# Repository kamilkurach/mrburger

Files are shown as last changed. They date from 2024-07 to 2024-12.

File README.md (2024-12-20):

# mrburger - mobile robot

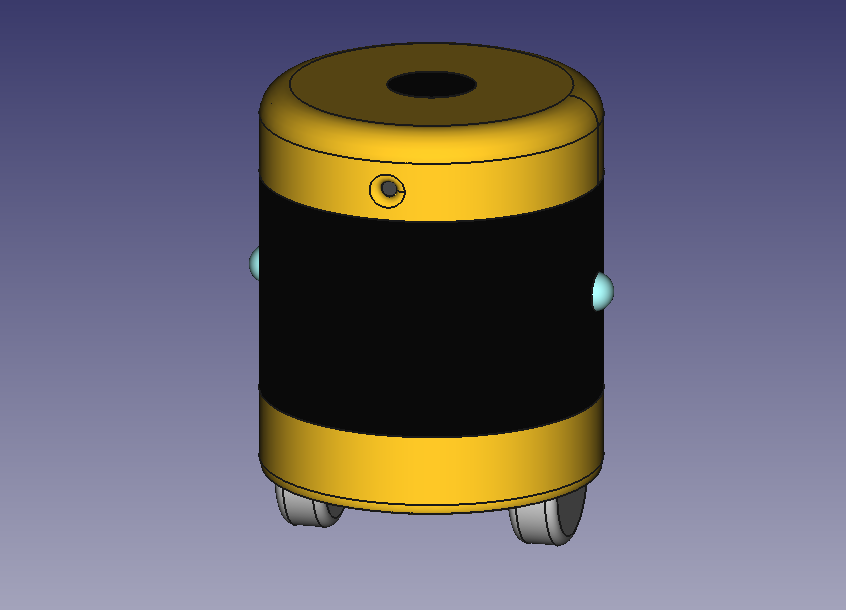
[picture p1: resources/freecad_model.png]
freecad

<!-- <img src="resources/IMG_20241218_102031.jpg" alt="currentstate" width=30%/> -->

## current state:

<!-- <img src="resources/IMG_20241204_015451.jpg" alt="currentstate" width=30%/> -->
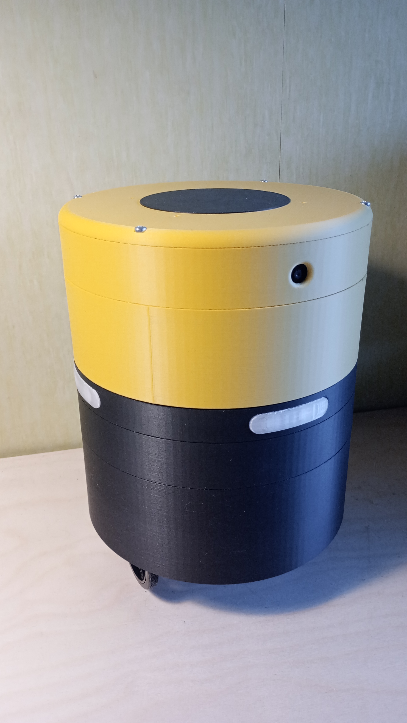
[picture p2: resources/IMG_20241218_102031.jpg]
currentstate


HARDWARE progress

SOFTWARE progress

## videos: 

https://youtube.com/shorts/dS5dcS42dTs

https://youtube.com/shorts/08CZh5qDslI

https://youtube.com/shorts/WGJIwH7I2C0 *latest*

## additional info and multimedia:

https://x.com/kamil_kurach

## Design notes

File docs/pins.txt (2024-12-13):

#GPIO12 PWMA -> PWM hardware pin (less overhead on CPU)

#GPIO13 PWMB -> PWM hardware pin (less overhead on CPU)

#GPIO4 STBY -> power saving on/off

#GPIO6 AIN2 -> controls motor spin direction

#GPIO5 AIN1 -> controls motor spin direction

#GPIO26 BIN1 -> controls motor spin direction

#GPIO19 BIN2 -> controls motor spin direction

#GPIO22 -> gpio-shutdown button

#GPIO27 -> 

#GPIO10 -> led SPI0

#GPIO2 SDA -> 9DoF IMU 
   
#GPIO3 SCL -> 9DoF IMU

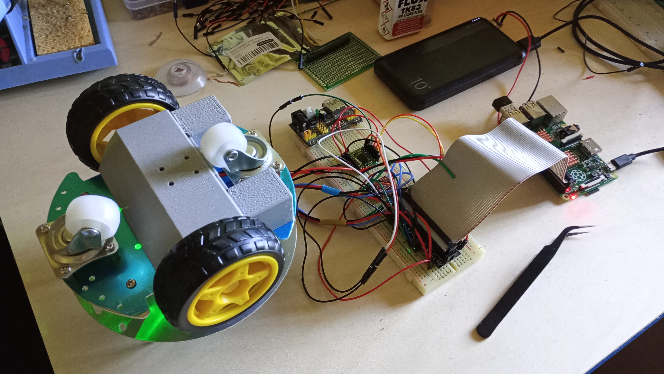
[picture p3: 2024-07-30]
resources/IMG_20240730_090038_dust_cover.jpg

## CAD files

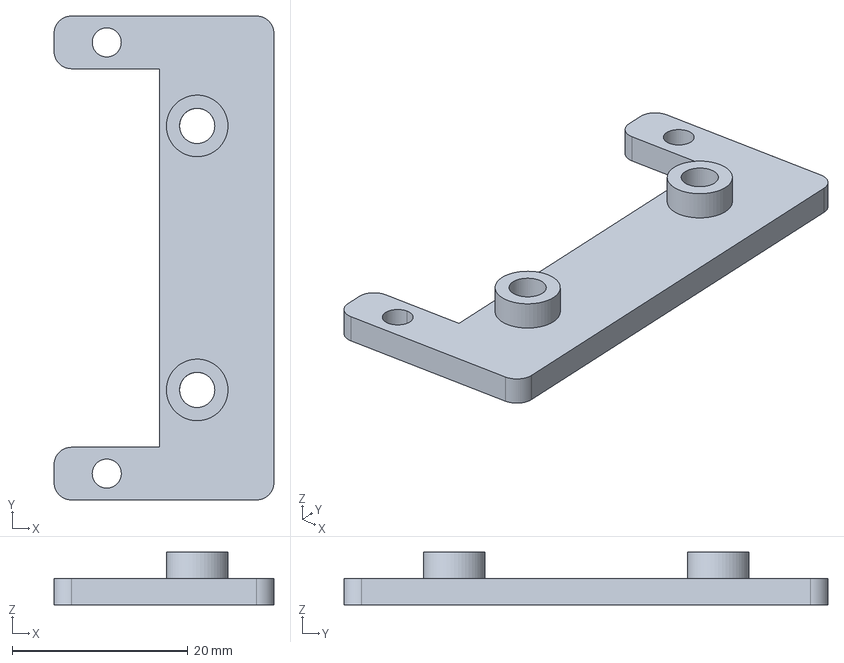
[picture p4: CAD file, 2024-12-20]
freecad/mrburger_usb_switch_panel_bracket.FCStd
25.0 x 55.0 x 6.00 mm

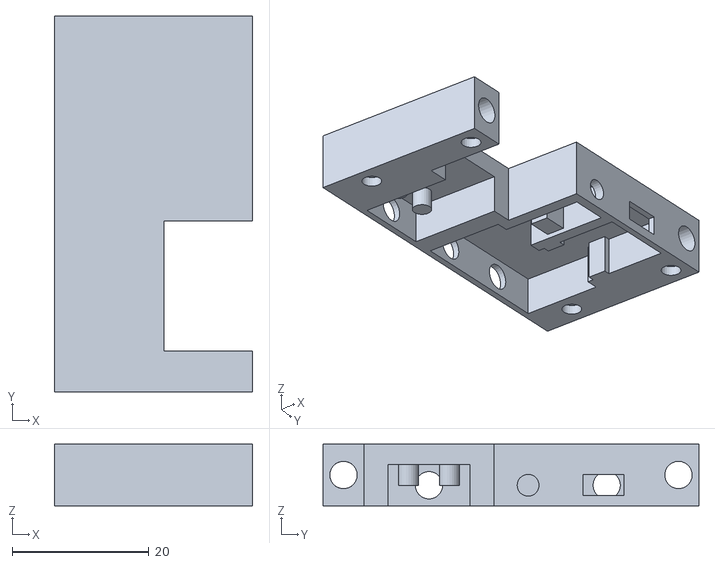
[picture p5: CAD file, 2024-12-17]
stl/mrburger_usb_switch_panel_bottom_panel.stl
29.0 x 55.0 x 9.00

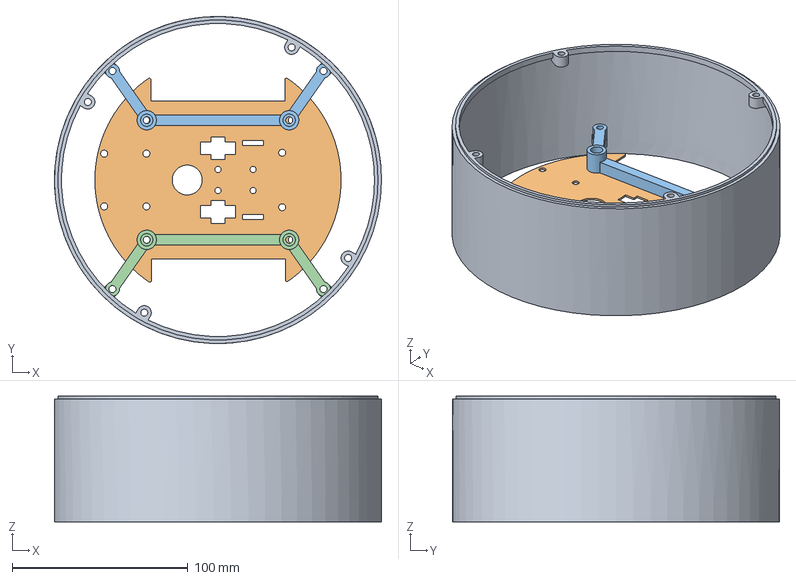
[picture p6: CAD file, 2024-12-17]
freecad/mrburger_bottom_ring.FCStd
186.0 x 186.0 x 71.5 mm
bottom_ring
mrburger_bottom_plate
mrburger_bracket_2
mrburger_bracket_003

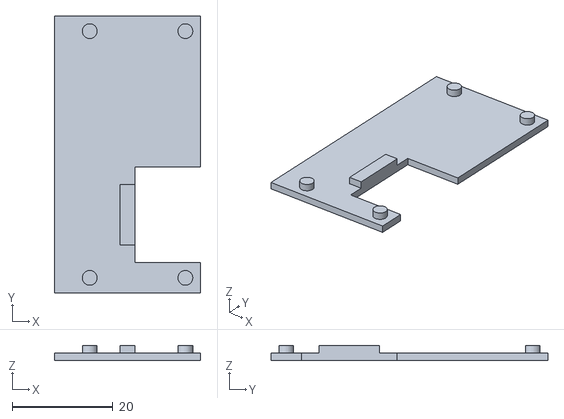
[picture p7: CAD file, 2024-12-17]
stl/mrburger_usb_switch_panel_lid.stl
29.0 x 55.0 x 3.00

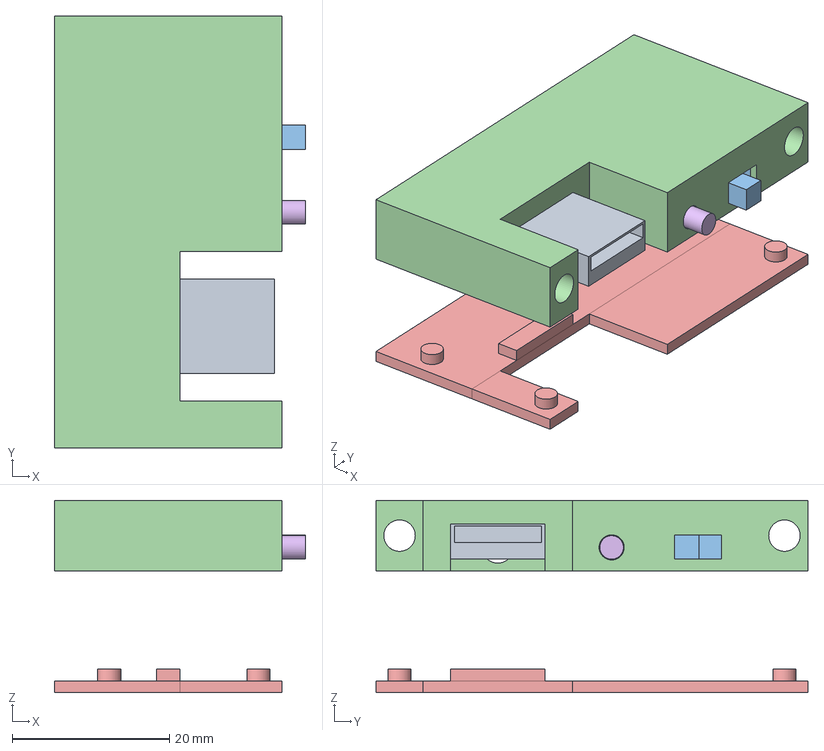
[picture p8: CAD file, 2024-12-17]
freecad/mrburger_usb_switch_panel.FCStd
32.0 x 55.0 x 24.5 mm
usb_type_A
push_button
switch
panel
lid
push_button_pin

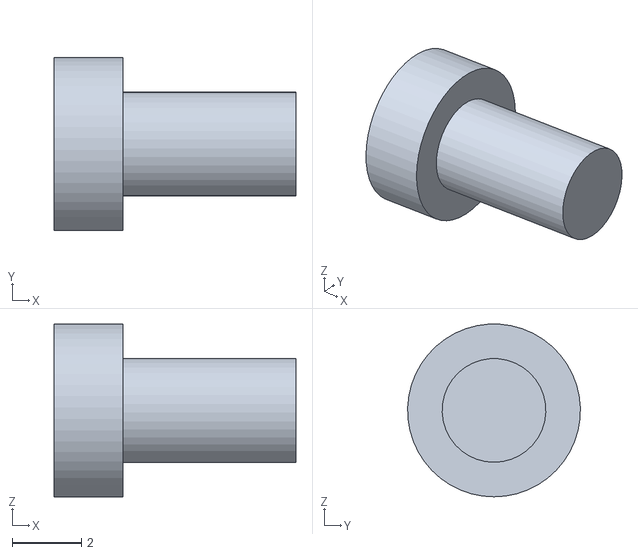
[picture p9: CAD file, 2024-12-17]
stl/mrburger_usb_switch_panel_button_pin.stl
7.00 x 5.00 x 4.99

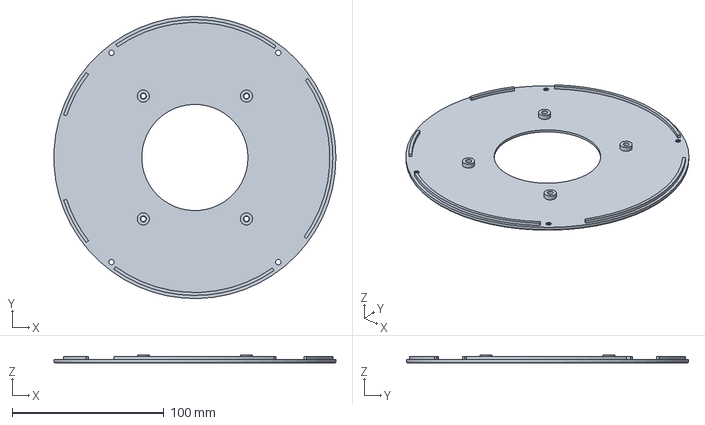
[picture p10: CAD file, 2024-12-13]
freecad/mrburger_universal_top_hat.FCStd
185.9 x 185.9 x 5.50 mm

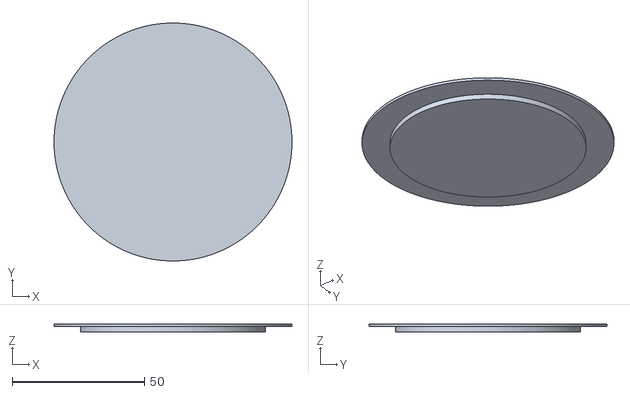
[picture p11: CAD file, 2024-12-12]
stl/mrburger_black_lid.stl
90.0 x 90.0 x 3.00

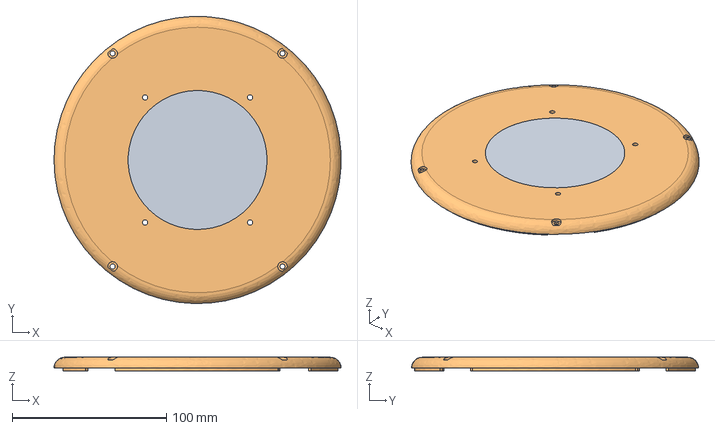
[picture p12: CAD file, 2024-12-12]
freecad/mrburger_top_hat.FCStd
185.9 x 185.9 x 8.80 mm
black_lid
yellow_hat

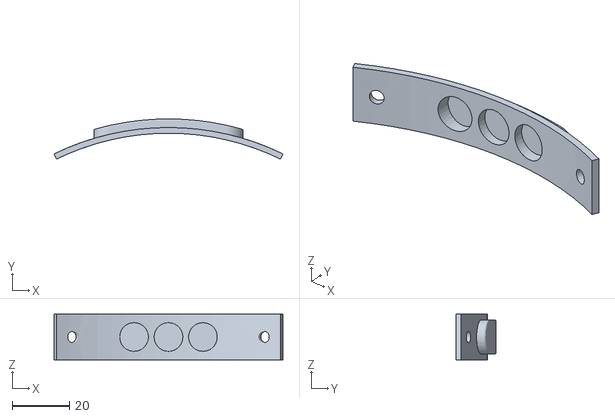
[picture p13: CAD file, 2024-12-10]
stl/mrburger_mid_led_ring_2_led_cover_2.2.stl
79.8 x 14.0 x 16.0

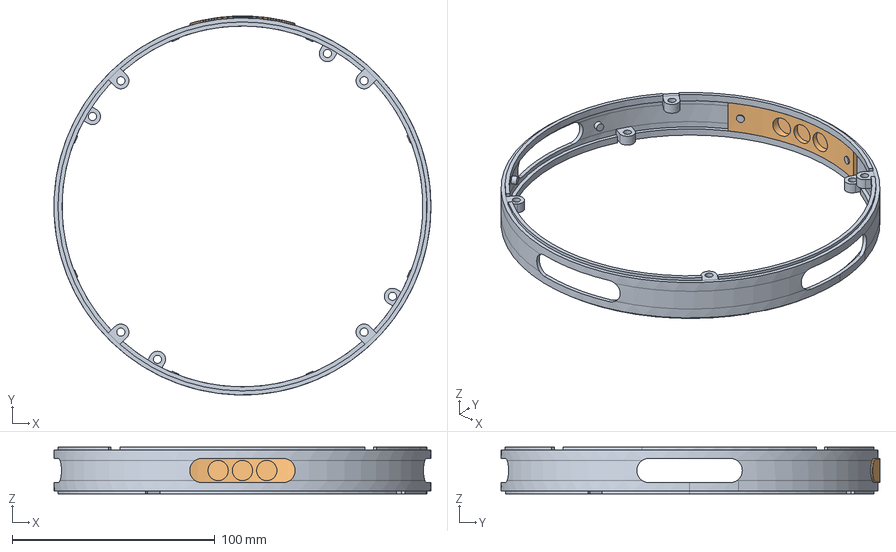
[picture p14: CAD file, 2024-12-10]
freecad/mrburger_mid_led_ring_2.2.FCStd
186.0 x 186.9 x 23.0 mm
led_ring
led_cover

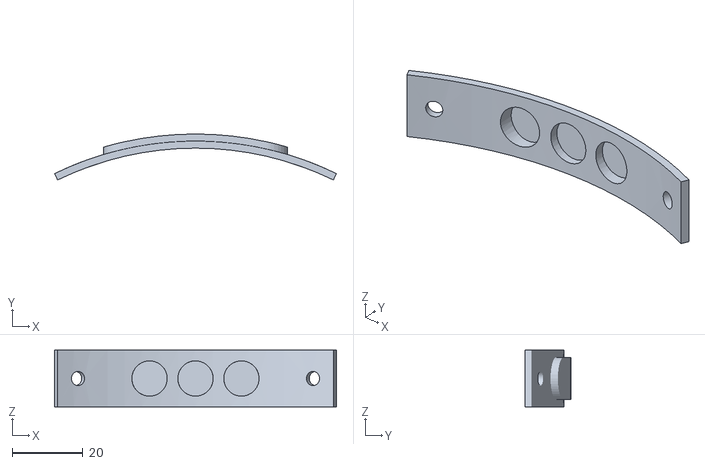
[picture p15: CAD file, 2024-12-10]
stl/mrburger_mid_led_ring_2_led_cover.stl
79.8 x 13.0 x 16.0

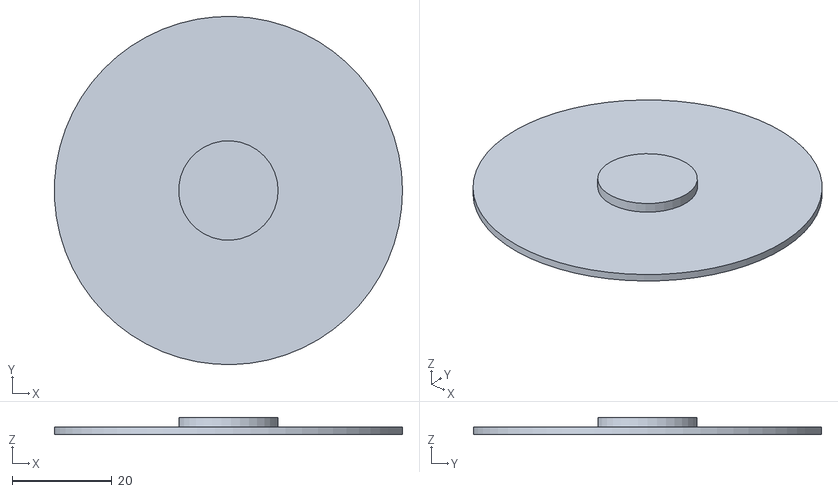
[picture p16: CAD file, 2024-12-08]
stl/mrburger_universal_black_lid.stl
70.0 x 70.0 x 3.50

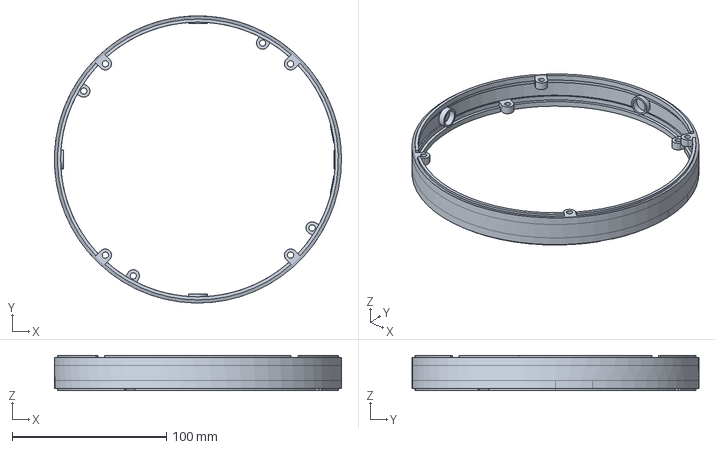
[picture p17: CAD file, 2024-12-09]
freecad/mrburger_mid_led_ring.FCStd
186.0 x 186.0 x 23.0 mm

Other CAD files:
freecad/mrburger_mid_led_ring_2.FCStd
stl/mrburger_induction_coil_bracket_coil_cover.stl
freecad/mrburger_bottom_hat.FCStd
stl/mrburger_induction_coil_bracket_electronics_cover.stl
freecad/mrburger_Li-Po_power_tray.FCStd
freecad/mrburger_bottom.FCStd
freecad/mrburger_bottom_plate.FCStd
freecad/mrburger_bracket.FCStd
freecad/mrburger_bracket_2.FCStd
freecad/mrburger_camera_bracket.FCStd
freecad/mrburger_camera_module.FCStd
freecad/mrburger_chassis.FCStd
freecad/mrburger_encoder_dust_cover.FCStd
freecad/mrburger_encoder_dust_cover_2.FCStd
freecad/mrburger_encoder_dust_cover_3.FCStd
freecad/mrburger_encoder_spacer.FCStd
freecad/mrburger_fan_inlet.FCStd
freecad/mrburger_hat.FCStd
freecad/mrburger_hat_light.FCStd
freecad/mrburger_imu.FCStd
freecad/mrburger_imu_mount.FCStd
freecad/mrburger_imu_pin.FCStd
freecad/mrburger_induction_coil_bracke_2.FCStd
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

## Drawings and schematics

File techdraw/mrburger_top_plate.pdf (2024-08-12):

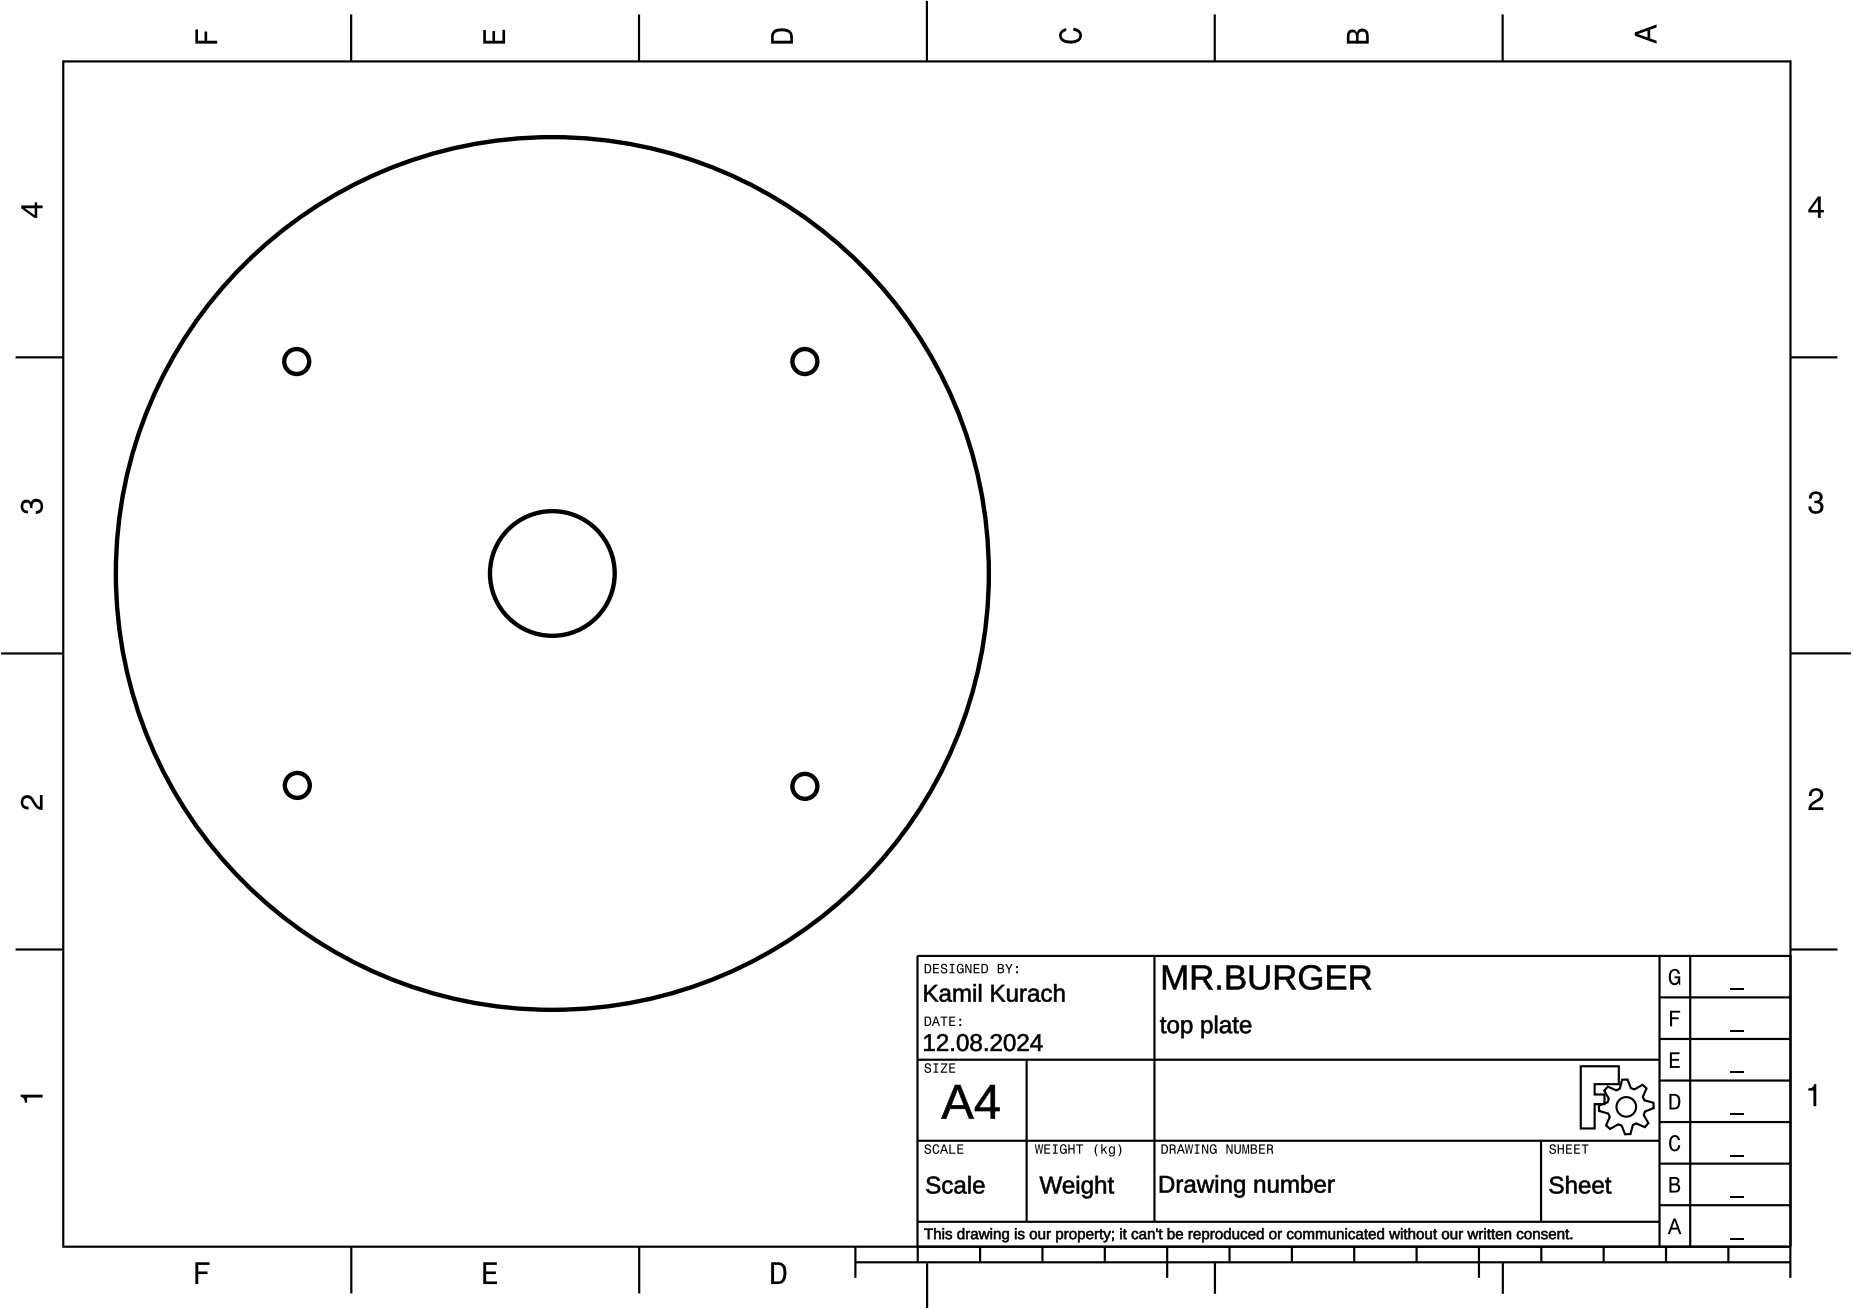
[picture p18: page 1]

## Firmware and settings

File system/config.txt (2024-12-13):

# For more options and information see
# http://rptl.io/configtxt
# Some settings may impact device functionality. See link above for details

# Uncomment some or all of these to enable the optional hardware interfaces
dtparam=i2c_arm=on
#dtparam=i2s=on
dtparam=spi=on

# Enable audio (loads snd_bcm2835)
dtparam=audio=off

# Additional overlays and parameters are documented
# /boot/firmware/overlays/README

# Automatically load overlays for detected cameras
camera_auto_detect=1

# Automatically load overlays for detected DSI displays
display_auto_detect=1

# Automatically load initramfs files, if found
auto_initramfs=1

# Enable DRM VC4 V3D driver
dtoverlay=vc4-kms-v3d
max_framebuffers=2

# Don't have the firmware create an initial video= setting in cmdline.txt.
# Use the kernel's default instead.
disable_fw_kms_setup=1

# Disable compensation for displays with overscan
disable_overscan=1

# Run as fast as firmware / board allows
arm_boost=1

# push button off
dtoverlay=gpio-shutdown,gpio_pin=22

[cm4]
# Enable host mode on the 2711 built-in XHCI USB controller.
# This line should be removed if the legacy DWC2 controller is required
# (e.g. for USB device mode) or if USB support is not required.
otg_mode=1

[cm5]
dtoverlay=dwc2,dr_mode=host

[all]
#arm_freq=800
#core_freq=250
#sdram_freq=400
#over_voltage=0
enable_uart=1

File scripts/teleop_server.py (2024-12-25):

import RPi.GPIO as GPIO
import pigpio
from time import sleep
import threading
import sys
import socket
from led import right_turn, left_turn, stop_light, forward_light_on, forward_light_off

GPIO.setmode(GPIO.BCM)

#GPIO12 PWMA
#GPIO.setup(12, GPIO.OUT)
#GPIO13 PWMB
#GPIO.setup(13, GPIO.OUT)

#GPIO4 STBY
GPIO.setup(4, GPIO.OUT)
GPIO.output(4, GPIO.HIGH)

def backwards():
  #GPIO6 AIN2
  GPIO.setup(6, GPIO.OUT)
  GPIO.output(6, GPIO.HIGH)

  #GPIO5 AIN1
  GPIO.setup(5, GPIO.OUT)
  GPIO.output(5, GPIO.LOW)

  #GPIO26 BIN1
  GPIO.setup(26, GPIO.OUT)
  GPIO.output(26, GPIO.LOW)

  #GPIO19 BIN2
  GPIO.setup(19, GPIO.OUT)
  GPIO.output(19, GPIO.HIGH)

def forward():
  #GPIO6 AIN2
  GPIO.setup(6, GPIO.OUT)
  GPIO.output(6, GPIO.LOW)

  #GPIO5 AIN1
  GPIO.setup(5, GPIO.OUT)
  GPIO.output(5, GPIO.HIGH)

  #GPIO26 BIN1
  GPIO.setup(26, GPIO.OUT)
  GPIO.output(26, GPIO.HIGH)

  #GPIO19 BIN2
  GPIO.setup(19, GPIO.OUT)
  GPIO.output(19, GPIO.LOW)

def turn_right():
  #GPIO6 AIN2
  GPIO.setup(6, GPIO.OUT)
  GPIO.output(6, GPIO.HIGH)

  #GPIO5 AIN1
  GPIO.setup(5, GPIO.OUT)
  GPIO.output(5, GPIO.LOW)

  #GPIO26 BIN1
  GPIO.setup(26, GPIO.OUT)
  GPIO.output(26, GPIO.HIGH)

  #GPIO19 BIN2
  GPIO.setup(19, GPIO.OUT)
  GPIO.output(19, GPIO.LOW)

def turn_left():
  #GPIO6 AIN2
  GPIO.setup(6, GPIO.OUT)
  GPIO.output(6, GPIO.LOW)

  #GPIO5 AIN1
  GPIO.setup(5, GPIO.OUT)
  GPIO.output(5, GPIO.HIGH)

  #GPIO26 BIN1
  GPIO.setup(26, GPIO.OUT)
  GPIO.output(26, GPIO.LOW)

  #GPIO19 BIN2
  GPIO.setup(19, GPIO.OUT)
  GPIO.output(19, GPIO.HIGH)

def soft_stop():
  #GPIO6 AIN2
  GPIO.setup(6, GPIO.OUT)
  GPIO.output(6, GPIO.LOW)

  #GPIO5 AIN1
  GPIO.setup(5, GPIO.OUT)
  GPIO.output(5, GPIO.LOW)

  #GPIO26 BIN1
  GPIO.setup(26, GPIO.OUT)
  GPIO.output(26, GPIO.LOW)

  #GPIO19 BIN2
  GPIO.setup(19, GPIO.OUT)
  GPIO.output(19, GPIO.LOW)


#left sensor
GPIO.setup(22, GPIO.IN)
#right sensor
GPIO.setup(27, GPIO.IN)

#set gpio25 to 50Hz
#pwm_a = GPIO.PWM(12, 50)
#pwm_b = GPIO.PWM(13, 50)

PI = pigpio.pi()
#PI.hardware_PWM(12, 50000, 400000)
#PI.hardware_PWM(13, 50000, 400000)

#pwm_a.start(0)
#pwm_b.start(0)

#set global vars initial values
PREV_TICK = GPIO.input(22)
TOTAL_TICKS = 0
TARGET_REACHED = False

'''
def calc_distance(tick_count):
  #returned distance in mm
  #wheel circumference 67 mm
  tick_per_revolution = 40
  distance = 67 * tick_count/tick_per_revolution
  return distance

def count_ticks(gpio):
  global TOTAL_TICKS
  global PREV_TICK
  global TARGET_REACHED
  while True:
    left_encoder = GPIO.input(gpio)
    if left_encoder == 1 and PREV_TICK == 0:
      TOTAL_TICKS += 1
    elif left_encoder == 0 and PREV_TICK == 1:
      TOTAL_TICKS += 1
    PREV_TICK = left_encoder
  #print("TT: ",TOTAL_TICKS,"PT: ",PREV_TICK)

def print_sensor_data():
  left_encoder = GPIO.input(22)
  right_encoder = GPIO.input(27)
  print("L: ", left_encoder, "R: ", right_encoder)

'''
#t_r = threading.Thread(target=right_turn, args=(3,))
#t.start()
#t_l = threading.Thread(target=left_turn, args=(3,))

host = '192.168.5.111'
socket = socket.socket(socket.AF_INET, socket.SOCK_STREAM)
socket.bind((host, 8080))
socket.listen(1)
connection, address = socket.accept()

current_state = None

forward_light_on()

while True:
  buffer = connection.recv(1024)
  if len(buffer) > 0:
    if str(buffer.decode()) == 'w':
      print(buffer)
      #soft_stop()
      #pwm_a.ChangeDutyCycle(0)
      #pwm_b.ChangeDutyCycle(0)
      #sleep(0.1)
      forward()
      PI.hardware_PWM(12, 50000, 400000)
      PI.hardware_PWM(13, 50000, 400000)
      #pwm_a.ChangeDutyCycle(40)
      #pwm_b.ChangeDutyCycle(40)
    elif str(buffer.decode()) == 'x':
      forward()
      PI.hardware_PWM(12, 50000, 650000)
      PI.hardware_PWM(13, 50000, 650000)
    elif str(buffer.decode()) == 's':
      print(buffer)
      soft_stop()
      #pwm_a.ChangeDutyCycle(0)
      #pwm_b.ChangeDutyCycle(0)
      PI.hardware_PWM(12, 50000, 0)
      PI.hardware_PWM(13, 50000, 0)
      sleep(0.2)
      backwards()
      PI.hardware_PWM(12, 50000, 400000)
      PI.hardware_PWM(13, 50000, 400000)
    elif str(buffer.decode()) == 'l':
      print(buffer)
      soft_stop()
      sleep(0.2)
      # rotate in place 
      turn_left()
      #if t_r.is_alive() == False:
      #  t_r.start()
      #  t_r.join()
      PI.hardware_PWM(12, 50000, 400000)
      PI.hardware_PWM(13, 50000, 400000)
      sleep(1.8)
      PI.hardware_PWM(12, 50000, 0)
      PI.hardware_PWM(13, 50000, 0)
    elif str(buffer.decode()) == 'a':
      print(buffer)
      forward()
      #right_turn(1)
      #if t_r.is_alive() == False:
      #  t_r.start()
      #  t_r.join()
      PI.hardware_PWM(12, 50000, 550000)
      PI.hardware_PWM(13, 50000, 350000)
    elif str(buffer.decode()) == 'r':
      print(buffer)
      soft_stop()
      sleep(0.2)
      # rotate in place 
      turn_right()
      #if t_r.is_alive() == False:
      #  t_r.start()
      #  t_r.join()
      PI.hardware_PWM(12, 50000, 400000)
      PI.hardware_PWM(13, 50000, 400000)
      sleep(1.8)
      PI.hardware_PWM(12, 50000, 0)
      PI.hardware_PWM(13, 50000, 0)
    elif str(buffer.decode()) == 'd':
      print(buffer)
      forward()
      #left_turn(1)
      #if t_l.is_alive() == False:
      #  t_l.start()
      #  t_l.join()
      PI.hardware_PWM(12, 50000, 350000)
      PI.hardware_PWM(13, 50000, 550000)
    elif str(buffer.decode()) == 'b':
      print(buffer)
      soft_stop()
      PI.hardware_PWM(12, 50000, 0)
      PI.hardware_PWM(13, 50000, 0)
      stop_light(1)
      forward_light_on()
    elif str(buffer.decode()) == 'q':
      print(buffer)
      soft_stop()
      #pwm_a.stop()
      #pwm_b.stop()
      PI.hardware_PWM(12, 50000, 0)
      PI.hardware_PWM(13, 50000, 0)
      forward_light_off()
      connection.close()
      #init STBY
      GPIO.output(4, GPIO.LOW)
      break

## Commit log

2024-02-28 Add powerbank holder model
    [mrburger-tracer_powerbank_holder.stl]
2024-02-28 Add powerbark holder in step format
    [mrburger-tracer_powerbank_holder.step]
2024-03-02 Add powerbank holder v2 (metal insert M3)
    [mrburger-tracer_powerbank_holder_v2.step, mrburger-tracer_powerbank_holder_v2.stl]
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2024-07-20 Move files to subfolders
    [mrburger-tracer_powerbank_holder.stl, mrburger-tracer_powerbank_holder_v2.stl, mrburger_bottom_plate.FCStd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]
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2024-07-21 Add sensor holder 2 and spacer model
    [mrburger_sensor_holder_2.stl, mrburger_sensor_spacer.stl]
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2024-07-23 Add latest sensor holder
    [mrburger_sensor_holder_3.stl]
2024-07-24 Add latest motor holder design
    [mrburger_motor_holder.FCStd, mrburger_motor_holder_2.stl]
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2024-07-29 Update chassis with new parts
    [mrburger_chassis.FCStd]
2024-07-29 Add latest bottom plate design
    [mrburger_bottom_plate.FCStd, mrburger_bottom_plate.stl]
2024-07-29 Add motor holder to chassis and cleanup
    [mrburger_chassis.FCStd, mrburger_motor_holder.FCStd]
2024-07-29 Add latest motor holder design (move holes)
    [mrburger_motor_holder.FCStd, mrburger_motor_holder_4.stl]
2024-07-29 Add dust cover for encoders
    [mrburger_encoder_dust_cover.FCStd, mrburger_encoder_dust_cover.stl]
2024-07-30 Add extended dust cover for encoders and motors
    [mrburger_encoder_dust_cover.FCStd, mrburger_encoder_dust_cover_2.stl]
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2024-07-31 Add encoder dust cover mk2
    [mrburger_encoder_dust_cover_2.FCStd, mrburger_encoder_dust_cover_2.stl]
2024-08-01 Add encoder dust cover mk3 (short with top sensors cover)
    [mrburger_encoder_dust_cover_3.FCStd, mrburger_encoder_dust_cover_3.stl]
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2024-08-03 Change extend and fillet size
    [mrburger_encoder_dust_cover_3.FCStd, mrburger_encoder_dust_cover_3.stl]
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2024-08-06 Add fan inlet stl file
    [mrburger_fan_inlet.stl]
2024-08-08 Add top plate model
    [mrburger_top_plate.FCStd]
2024-08-08 Update top plate model
    [mrburger_top_plate.FCStd]
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2024-08-08 Add imu mount model
    [mrburger_imu_mount.FCStd, mrburger_imu_mount_bottom.stl, mrburger_imu_mount_top_cover.stl]
2024-08-09 Add plastic pin as a non-magnetic screw replacement
    [mrburger_imu_mount_bottom_pin.stl, mrburger_imu_pin.FCStd]
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2024-08-09 Add mounting screw (pin) and tube
    [M3.5-tube.stl, M3.5.stl]
2024-08-10 Add front and back wheel spacer model
    [mrburger_wheel_spacer.FCStd, mrburger_wheel_spacer.stl]
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2024-08-10 Add top cover (hat) concept
    [mrburger_hat.FCStd]
2024-08-11 Update camera module model
    [mrburger_camera_module.FCStd, mrburger_camera_module.stl]
2024-08-11 Add camera mounting point
    [mrburger_hat.FCStd]
2024-08-11 Add light version of hat (less printing time ~17H)
    [mrburger_hat_light.FCStd]
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2024-08-11 Update plate model (change holes placement)
    [mrburger_top_plate.FCStd]
2024-08-11 Add hat stl model (heavy)
    [mrburger_hat.stl]
2024-08-12 Add top plate and techdraw (original -> misaligned holes)
    [mrburger_top_plate_original.FCStd]
2024-08-13 Add top plate model for printing
    [mrburger_top_plate_for_printing.stl, mrburger_top_plate_original_for_printing.FCStd]
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2024-08-17 Add latest spacer model
    [mrburger_wheel_spacer.stl]
2024-08-18 Update chassis concept model
    [mrburger_chassis.FCStd]
2024-08-18 Add temp camera holder
    [mrburger_temp_camera_holder.FCStd]
2024-08-18 Add turn signals to chassis concept model
    [mrburger_chassis.FCStd]
2024-08-18 Add temp side wheels
    [mrburger_chassis.FCStd]
2024-08-25 Init kicad carrier board project
    [mrburger_bottom.FCStd, mrburger_carrier_board.kicad_pcb, mrburger_carrier_board.kicad_sch]
2024-11-15 Upadte tmp camera holder design
    [mrburger_temp_camera_holder.FCStd]
2024-11-15 Update tmp camera holder design
    [mrburger_temp_camera_holder.FCStd]
2024-11-15 Replace tmp camera holder with new design
    [mrburger_temp_camera_holder.FCStd, mrburger_tmp_camera_holder-clip.stl, mrburger_tmp_camera_holder.FCStd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]
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2024-11-18 Add wheel extender (5 degree angle)
    [mrburger_wheel_spacer_n_extender.FCStd]
2024-11-19 Add trun signal concept (2 led)
    [mrburger_turn_signal_2.FCStd]
2024-11-19 Add tmp led holder
    [mrburger_tmp_led_holder.FCStd, mrburger_tmp_led_holder.stl]
2024-11-19 Update tmp led holder (2 led)
    [mrburger_tmp_led_holder.FCStd, mrburger_tmp_led_holder.stl]
2024-11-20 Add motor shaft-wheel spacer
    [mrburger_motor_wheel_spacer.FCStd, mrburger_motor_wheel_spacer.stl]
2024-11-20 Add new motor model
    [mrburger_motor_6v_60:1.FCStd, mrburger_motor_6v_60:1.stl]
2024-11-21 Add wheel and tire concept
    [mrburger_wheel_n_tire_test.FCStd]
2024-11-21 Add led ring concept
    [mrburger_led_ring.FCStd]
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2024-11-22 Change for WS2812 smd led
    [mrburger_turn_signal.FCStd, mrburger_turn_signal.stl]
2024-11-22 Add turn signal ring
    [mrburger_turn_signal.FCStd, mrburger_turn_signal.stl, mrburger_turn_signal_ring.stl]
2024-11-22 Add ultrasonic sensor model
    [mrburger_ultrasonic_sensor.FCStd]
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2024-11-23 Fix holes placement
    [mrburger_wheel_spacer.FCStd]
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2024-11-23 Add new motor holder for 60:1 6v motors (draft)
    [mrburger_motor_holder_2.FCStd]
2024-11-23 Update motor holder for 60:1 6v motors (draft)
    [mrburger_motor_holder_2.FCStd]
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2024-11-24 Update motor holder model (more room for motors)
    [mrburger_motor_holder_2.FCStd, mrburger_motor_holder_60:1_6v.stl]
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2024-11-25 Update motor clamp model (fix collision with motor holder)
    [mrburger_motor_holder_2.FCStd, mrburger_motor_holder_60:1_6v_clamp.stl]
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2024-11-30 Add ring module v2 with smaller dimensions 91x93 (draft)
    [mrburger_ring_2.FCStd]
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2024-12-02 Fix for camera tape and locking pins
    [mrburger_camera_bracket.FCStd, mrburger_camera_bracket.stl]
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2024-12-05 Fix dimensions and simplify coil bracket
    [mrburger_induction_coil_bracket.FCStd, mrburger_induction_coil_bracket.stl, mrburger_induction_coil_bracket_coil_cover.stl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]
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2024-12-05 Fix tube dimensions
    [mrburger_induction_coil_bracket.FCStd, mrburger_induction_coil_bracket_distance_tube.stl]
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2024-12-16 Add bottom ring with mounting point for usb and switch panel (draft)
    [mrburger_bottom_ring.FCStd, mrburger_bottom_ring_w_connector.FCStd]
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
